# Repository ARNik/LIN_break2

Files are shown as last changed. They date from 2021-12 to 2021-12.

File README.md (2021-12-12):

# LIN break

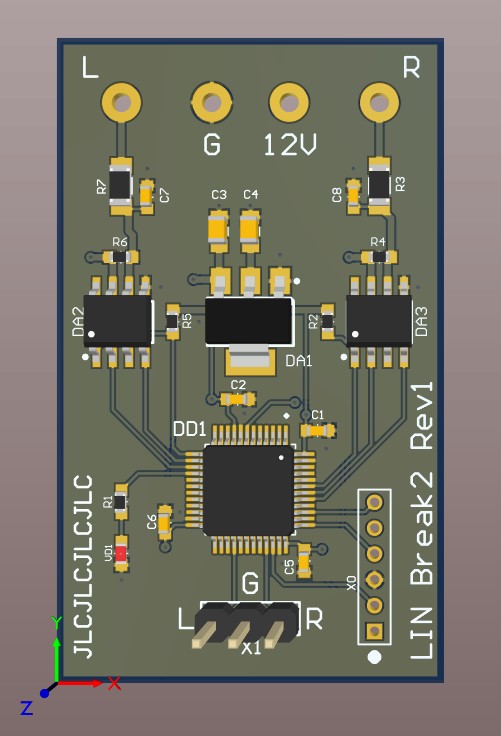
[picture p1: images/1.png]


This device allows you to analyze and reverse engineer LIN bus. 
It transmits LIN packets to two different outputs depending from packet source.

## Schematics and PCB Design

All source files are [available on Github](https://github.com/ARNik/LIN_break2).
The schematics and PCB layout are in Altium Designer format.

## Licenses

### Circuit Schematics

The circuit schematics of this project are made available under the
[CC-BY-SA](https://creativecommons.org/licenses/by-sa/3.0/) license.

### Hardware Design

 Open source hardware.

### Miscellenious

Data sheets, Altium libraries, 3D Models are subject to vendor specific
licensing.

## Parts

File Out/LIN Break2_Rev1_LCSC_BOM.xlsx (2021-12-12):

Comment | Designator | Footprint | LCSC Part #
1u | C1, C2, C5, C6 | C0603 | C15849
220p | C7, C8 | C0603
=Value | DA1 | AMS1117-3.3 | C426566
SN65HVDA195 | DA2, DA3 | TI-SOIC8 D | C140290
STM32F103C4 | DD1 | ST-LQFP48
1k | R1 | R0603 | C21190
10k | R2, R4, R5, R6 | R0603 | C21190
22 | R3, R7 | R1206
Red | VD1 | LTST-C193 RED | C157741
PLS-3 | X1 | PLS-3

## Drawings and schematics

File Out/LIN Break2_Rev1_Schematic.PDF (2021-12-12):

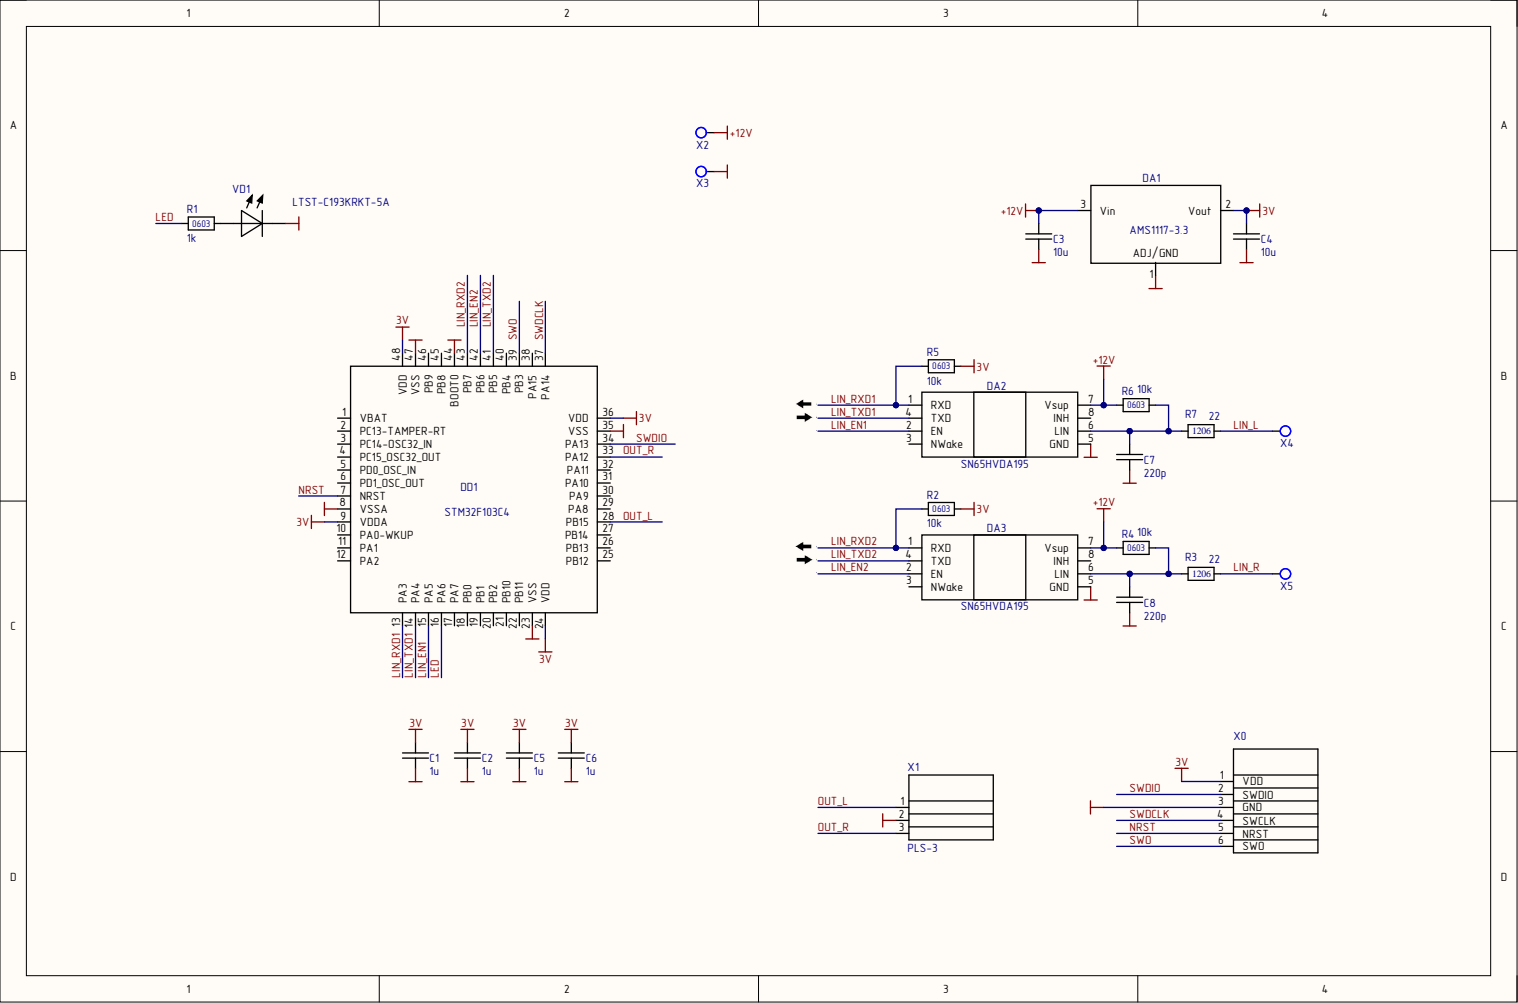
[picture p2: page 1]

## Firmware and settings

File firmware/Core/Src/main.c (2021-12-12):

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
/* Includes ------------------------------------------------------------------*/
#include "main.h"


void SystemClock_Config(void);
static void MX_GPIO_Init(void);
/**
  * @brief  The application entry point.
  * @retval int
  */
int main(void)
{
  /* MCU Configuration--------------------------------------------------------*/

  /* Reset of all peripherals, Initializes the Flash interface and the Systick. */
  HAL_Init();

  /* Configure the system clock */
  SystemClock_Config();

  /* Initialize all configured peripherals */
  MX_GPIO_Init();
  /* USER CODE BEGIN 2 */

  HAL_GPIO_WritePin(LIN_TXT1_GPIO_Port, LIN_TXT1_Pin, GPIO_PIN_SET);
  HAL_GPIO_WritePin(LIN_TXD2_GPIO_Port, LIN_TXD2_Pin, GPIO_PIN_SET);
  HAL_GPIO_WritePin(LIN_EN1_GPIO_Port, LIN_EN1_Pin, GPIO_PIN_SET);
  HAL_GPIO_WritePin(LIN_EN2_GPIO_Port, LIN_EN2_Pin, GPIO_PIN_SET);

  HAL_GPIO_WritePin(OUT_L_GPIO_Port, OUT_L_Pin, GPIO_PIN_SET);
  HAL_GPIO_WritePin(OUT_R_GPIO_Port, OUT_R_Pin, GPIO_PIN_SET);

  HAL_GPIO_WritePin(LED_GPIO_Port, LED_Pin, GPIO_PIN_SET);

  HAL_Delay(1000);

  enum
  {
	  Idle,
	  L_active,
	  R_active

  }state;

  state = Idle;

  /* USER CODE END 2 */

  /* Infinite loop */
  /* USER CODE BEGIN WHILE */
  while (1)
  {
	  if(state == Idle)
	  {
		  if(GPIO_PIN_RESET == HAL_GPIO_ReadPin(LIN_RXD1_GPIO_Port, LIN_RXD1_Pin))
		  {
			  state = L_active;
			  HAL_GPIO_WritePin(LIN_TXT1_GPIO_Port, LIN_TXT1_Pin, GPIO_PIN_SET);
			  HAL_GPIO_WritePin(LIN_TXD2_GPIO_Port, LIN_TXD2_Pin, GPIO_PIN_RESET);
			  HAL_GPIO_WritePin(OUT_L_GPIO_Port, OUT_L_Pin, GPIO_PIN_RESET);
			  HAL_GPIO_WritePin(LED_GPIO_Port, LED_Pin, GPIO_PIN_SET);
		  }
		  else if(GPIO_PIN_RESET == HAL_GPIO_ReadPin(LIN_RXD2_GPIO_Port, LIN_RXD2_Pin))
		  {
			  state = R_active;
			  HAL_GPIO_WritePin(LIN_TXT1_GPIO_Port, LIN_TXT1_Pin, GPIO_PIN_RESET);
			  HAL_GPIO_WritePin(LIN_TXD2_GPIO_Port, LIN_TXD2_Pin, GPIO_PIN_SET);
			  HAL_GPIO_WritePin(OUT_R_GPIO_Port, OUT_R_Pin, GPIO_PIN_RESET);
			  HAL_GPIO_WritePin(LED_GPIO_Port, LED_Pin, GPIO_PIN_SET);
		  }
	  }

	  if(state == L_active)
	  {
		  if(GPIO_PIN_SET == HAL_GPIO_ReadPin(LIN_RXD1_GPIO_Port, LIN_RXD1_Pin))
		  {
			  state = Idle;
			  HAL_GPIO_WritePin(LIN_TXT1_GPIO_Port, LIN_TXT1_Pin, GPIO_PIN_SET);
			  HAL_GPIO_WritePin(LIN_TXD2_GPIO_Port, LIN_TXD2_Pin, GPIO_PIN_SET);
			  HAL_GPIO_WritePin(OUT_L_GPIO_Port, OUT_L_Pin, GPIO_PIN_SET);
			  HAL_GPIO_WritePin(OUT_R_GPIO_Port, OUT_R_Pin, GPIO_PIN_SET);
			  HAL_GPIO_WritePin(LED_GPIO_Port, LED_Pin, GPIO_PIN_RESET);
		  }
	  }

	  if(state == R_active)
	  {
		  if(GPIO_PIN_SET == HAL_GPIO_ReadPin(LIN_RXD2_GPIO_Port, LIN_RXD2_Pin))
		  {
			  state = Idle;
			  HAL_GPIO_WritePin(LIN_TXT1_GPIO_Port, LIN_TXT1_Pin, GPIO_PIN_SET);
			  HAL_GPIO_WritePin(LIN_TXD2_GPIO_Port, LIN_TXD2_Pin, GPIO_PIN_SET);
			  HAL_GPIO_WritePin(OUT_L_GPIO_Port, OUT_L_Pin, GPIO_PIN_SET);
			  HAL_GPIO_WritePin(OUT_R_GPIO_Port, OUT_R_Pin, GPIO_PIN_SET);
			  HAL_GPIO_WritePin(LED_GPIO_Port, LED_Pin, GPIO_PIN_RESET);
		  }
	  }


    /* USER CODE END WHILE */

    /* USER CODE BEGIN 3 */
  }
  /* USER CODE END 3 */
}

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


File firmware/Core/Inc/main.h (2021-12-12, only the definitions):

#define LIN_RXD1_Pin GPIO_PIN_3
#define LIN_RXD1_GPIO_Port GPIOA
#define LIN_TXT1_Pin GPIO_PIN_4
#define LIN_TXT1_GPIO_Port GPIOA
#define LIN_EN1_Pin GPIO_PIN_5
#define LIN_EN1_GPIO_Port GPIOA
#define LED_Pin GPIO_PIN_6
#define LED_GPIO_Port GPIOA
#define OUT_L_Pin GPIO_PIN_15
#define OUT_L_GPIO_Port GPIOB
#define OUT_R_Pin GPIO_PIN_12
#define OUT_R_GPIO_Port GPIOA
#define LIN_TXD2_Pin GPIO_PIN_5
#define LIN_TXD2_GPIO_Port GPIOB
#define LIN_EN2_Pin GPIO_PIN_6
#define LIN_EN2_GPIO_Port GPIOB
#define LIN_RXD2_Pin GPIO_PIN_7
#define LIN_RXD2_GPIO_Port GPIOB

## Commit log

2021-12-10 BOM Template.xltx added
2021-12-12 pcb traced
    [LIN_break2.PcbDoc, LIN_break2.PrjPcb, LIN_break2.SchDoc]
2021-12-12 Outjob generated.
    [LIN Break2_Rev1_LCSC_BOM.xlsx, LIN Break2_Rev1_PickAndPlace.csv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]
2021-12-12 STM32CubeMX project added

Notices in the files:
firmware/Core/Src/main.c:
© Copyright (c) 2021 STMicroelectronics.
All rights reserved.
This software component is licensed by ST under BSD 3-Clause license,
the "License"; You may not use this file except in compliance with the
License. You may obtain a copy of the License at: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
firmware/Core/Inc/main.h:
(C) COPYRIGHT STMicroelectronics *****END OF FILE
